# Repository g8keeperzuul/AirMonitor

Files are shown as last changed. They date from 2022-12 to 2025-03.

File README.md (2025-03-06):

# AirMonitor #
## Indoor Environmental Sensor ##

Overview | Details
---|---
Language: | C++ 
IDE: | Platform.io (VS Code + Platform.io extension)
Microcontroller: |  Adafruit Feather M0

This custom device connects to wifi and publishes sensor readings via MQTT at the set refresh rate frequency.

This device will send Home Assistant compatible discovery messages via MQTT. It can be configured via special MQTT topics.

The software is modular and designed to be reused. It sacrifices simplicity, RAM and flash in order to minimize the amount of developer time needed to get a robust Home Assistant compliant MQTT device working. 
[Start here](lib/mqtt-ha-helper/README.md) to learn how to use the [mqtt-ha-helper](lib/mqtt-ha-helper/mqtt-ha-helper.cpp) to provide auto-discovery for sensors.
For providing auto-discovery for [static device diagnostics](lib/mqtt-ha-helper/Discovery_DiagnosticFact.md) as well as [measurable diagnostics](lib/mqtt-ha-helper/Discovery_MeasurableDiagnostic.md), the steps are slightly different. Finally to support interactive controls and remote configuration via MQTT, the device will need to listen on topics and provide state updates. The details on how to do so are [here](lib/mqtt-ha-helper/Discovery_Control.md).

Auto-discovery for:
* [sensors (start here)](lib/mqtt-ha-helper/README.md)
* [diagnostic facts](lib/mqtt-ha-helper/Discovery_DiagnosticFact.md)
* [measurable diagnostics](lib/mqtt-ha-helper/Discovery_MeasurableDiagnostic.md)
* [controls](lib/mqtt-ha-helper/Discovery_Control.md)

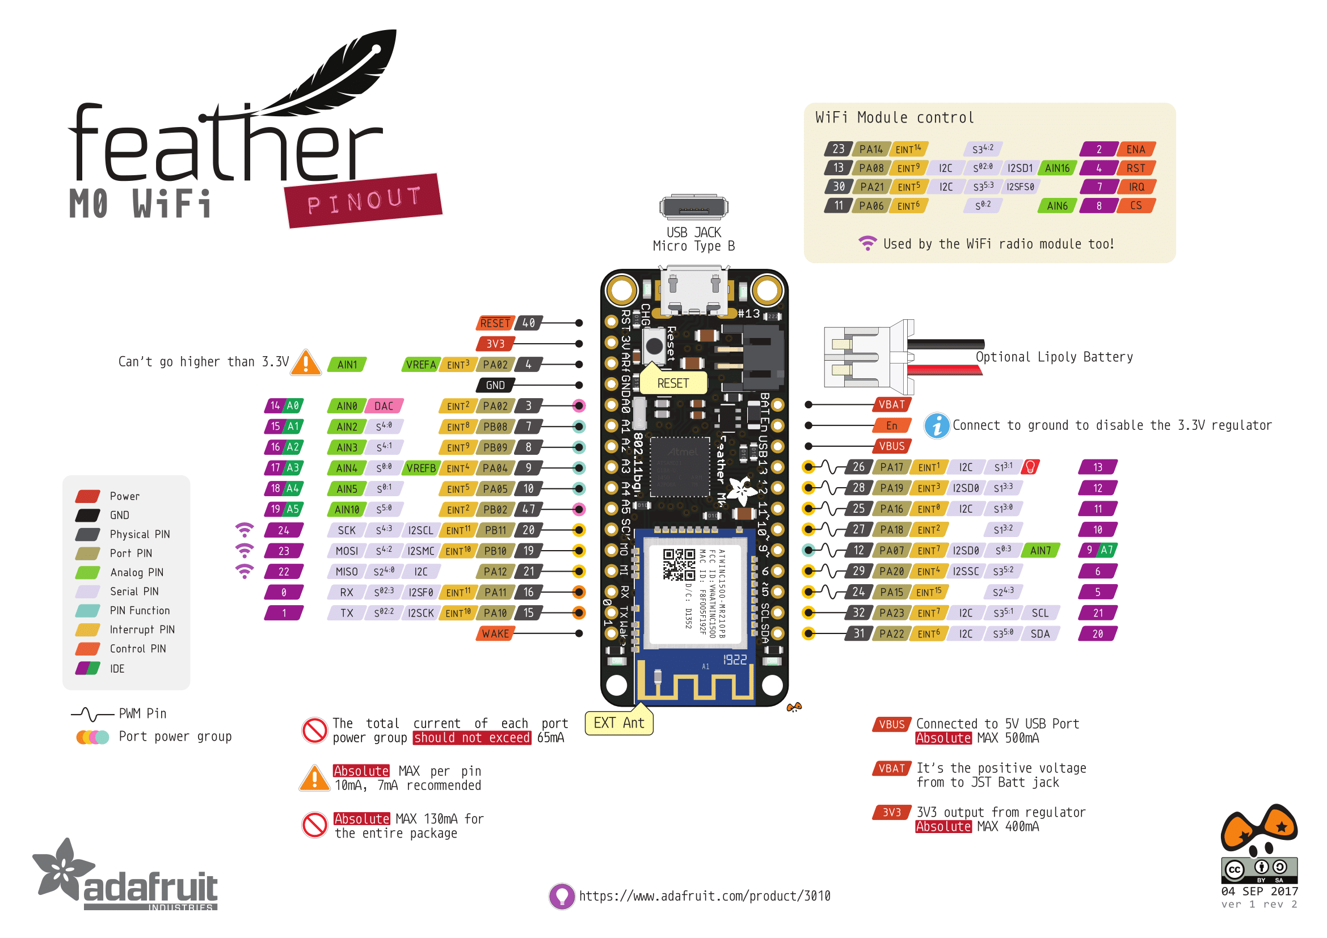
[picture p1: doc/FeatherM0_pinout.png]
Adafruit Feather M0+


Sensor | Measures...
---|---
SHT40 | humidity (% RH), temperature (C)
DPS310 | temperature (C), pressure (hectopascal, hPa), altitude computed
PM2.5 | particulate matter (Particles > 0.3um, 0.5um, 1.0um, 2.5um, 5.0um, 10.0um / 0.1L air); **AQI computed**
SCD30 | carbon dioxide (PPM direct from sensor), humidity (% RH), temperature (C)

[For physical build details, see here](doc/physical_build.md).

## How the Device Publishes Sensor State ##

MQTT Topic:
```
homeassistant/{device_type}/{device_id}/state 
homeassistant/sensor/featherm0/state
```

Sensor State Payload:
```
{
  "temperature": 22.05,
  "humidity": 38.25,
  "pressure": 989.4,
  "pressure_details": {
    "temperature": 21.25,
    "altitude": 281.3
  },
  "pm1": 1,
  "pm25": 1,
  "pm10": 1,
  "aqi": 4,
  "aqi_details": {
    "count_gt_03": 228,
    "count_gt_05": 68,
    "count_gt_10": 2,
    "count_gt_25": 0,
    "count_gt_50": 0,
    "count_gt_100": 0
  },
  "carbon_dioxide": 954,
  "carbon_dioxide_details": {
    "temperature": 23.5,
    "humidity": 35.54
  }
}
```

### Sensors Discovery ###

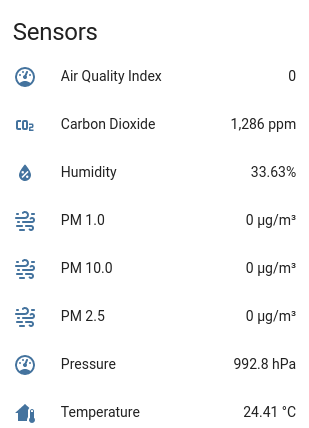
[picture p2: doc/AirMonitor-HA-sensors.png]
Sensors


All of the following sensors use the common sensor state topic (see below):

Sensor Discovery: 
```
homeassistant/sensor/featherm0/carbon_dioxide/config
homeassistant/sensor/featherm0/aqi/config
homeassistant/sensor/featherm0/pm1/config
homeassistant/sensor/featherm0/pm25/config
homeassistant/sensor/featherm0/pm10/config
homeassistant/sensor/featherm0/pressure/config
homeassistant/sensor/featherm0/humidity/config
homeassistant/sensor/featherm0/temperature/config
```

## How the Device Publishes Diagnostics ##

```
homeassistant/{device_type}/{device_id}/diagnostics
homeassistant/sensor/featherm0/diagnostics
```

Configuration State Payload:
```
{ 
"wifi_rssi": -42, 
"wifi_ip": "10.0.0.130", 
"wifi_mac": "96:e6:f1:05:f0:f8",
"sht40_heater_intensity": "Disabled", 
"sht40_heater_duration": 0, 
"sht40_precision": "High"
}
```

### Diagnostics Discovery ###
```
homeassistant/sensor/featherm0/wifi_rssi/config
homeassistant/sensor/featherm0/wifi_ip/config
homeassistant/sensor/featherm0/wifi_mac/config
homeassistant/sensor/featherm0/sht40_heater_intensity/config
homeassistant/sensor/featherm0/sht40_heater_duration/config
homeassistant/sensor/featherm0/sht40_precision/config
```

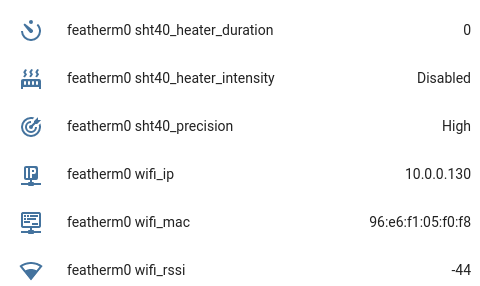
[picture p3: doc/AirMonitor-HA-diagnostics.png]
Diagnostics


## How the Device Publishes Controls ##

Controls/configuration must listen on topics to accept updates (setter or command topics) and reflect those changes back to the UI (getter or state topics). Unlike sensors or diagnostics, controls have a dedicated read and write topic per control that carry a single raw value such as an integer (not JSON).

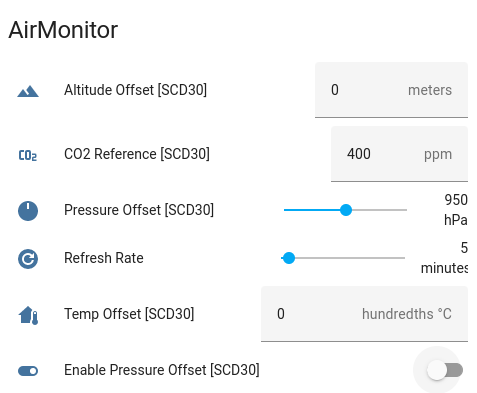
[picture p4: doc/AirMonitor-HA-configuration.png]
Controls


### Altitude Offset ###

Discovery: 
```
homeassistant/number/featherm0_altitude_offset/config
```
Altitude offset state: 
```
homeassistant/number/featherm0/altitude_offset/get
```
Altitude offset command: 
```
homeassistant/number/featherm0/altitude_offset/set
```

### Ambient Pressure Calibration ###

Discovery: 
```
homeassistant/switch/featherm0/use_pressure_offset/config
```
Use ambient pressure state: 
```
homeassistant/switch/featherm0/use_pressure_offset/get
```
Use ambient pressure command: 
```
homeassistant/switch/featherm0/use_pressure_offset/set
```

### Temperature Offset ###
Discovery: 
```
homeassistant/number/featherm0/temperature_offset/config
```
Temp Offset state: 
```
homeassistant/number/featherm0/temperature_offset/get
```
Temp Offset command: 
```
homeassistant/number/featherm0/temperature_offset/set
```

### Refresh Rate ###
Discovery: 
```
homeassistant/number/featherm0/refreshrate/config
```
Refresh rate state: 
```
homeassistant/number/featherm0/refreshrate/get
```
Refresh rate command: 
```
homeassistant/number/featherm0/refreshrate/set
```

### CO2 Calibration ###
Discovery: 
```
homeassistant/number/featherm0/co2_reference/config
```
Refresh rate state: 
```
homeassistant/number/featherm0/co2_reference/get
```
Refresh rate command: 
```
homeassistant/number/featherm0/co2_reference/set
```
See [how-to calibrate](doc/how-to-calibrate.md) for details.

## Software Dependencies ##

Feature | Library | Release
---|---|---
Wifi connectivity | https://github.com/arduino-libraries/WiFi101 | v0.16.1
MQTT connectivity | https://github.com/256dpi/arduino-mqtt | v2.5.0
DPS310 Barometric Pressure | https://github.com/adafruit/Adafruit_DPS310 | v1.1.1
SHT40 Temperature and Humidity | https://github.com/adafruit/Adafruit_SHT4X | v1.0.1
PM2.5 Air Quality | https://github.com/adafruit/Adafruit_PM25AQI | v1.0.6
SCD30 Carbon Dioxide | https://github.com/adafruit/Adafruit_SCD30 | v1.0.8

## Home Assistant Customizations ##

Update the default labels in the Home Assistant dashboard:
```
homeassistant:
  customize:
    sensor.featherm0_humidity:
      friendly_name: Humidity
    sensor.featherm0_temperature:
      friendly_name: Temperature
    sensor.featherm0_pressure:
      friendly_name: Pressure
    sensor.featherm0_aqi:
      friendly_name: Air Quality Index
    sensor.featherm0_pm1:
      friendly_name: PM 1.0
    sensor.featherm0_pm25:
      friendly_name: PM 2.5
    sensor.featherm0_pm10:
      friendly_name: PM 10.0
    sensor.featherm0_carbon_dioxide:
      friendly_name: Carbon Dioxide
    
    number.featherm0_altitude_offset:
      friendly_name: Altitude Offset [SCD30]
    number.featherm0_co2_reference:
      friendly_name: CO2 Reference [SCD30]
    number.featherm0_pressure_offset:
      friendly_name: Pressure Offset [SCD30]
    switch.featherm0_use_pressure_offset:
      friendly_name: Enable Pressure Offset [SCD30]
    number.featherm0_refreshrate:
      friendly_name: Refresh Rate
    number.featherm0_temperature_offset:
      friendly_name: Temp Offset [SCD30]
```
---
Tips:

To enable serial logging, see [log.h](lib/log/log.h)

To customize network configuration, copy [sample-env.h](src/sample-env.h) to env.h and apply your own local wifi and MQTT broker details.

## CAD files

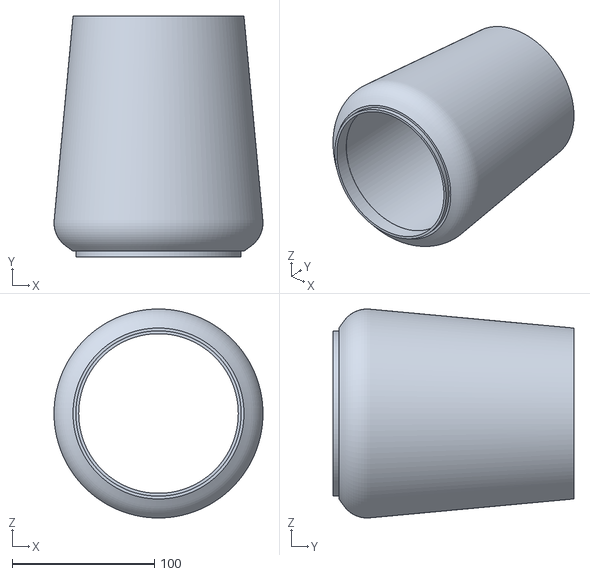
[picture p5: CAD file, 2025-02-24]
content/3d-model/Env-Sensor-Enclosure-body.stl
146.7 x 169.0 x 146.7

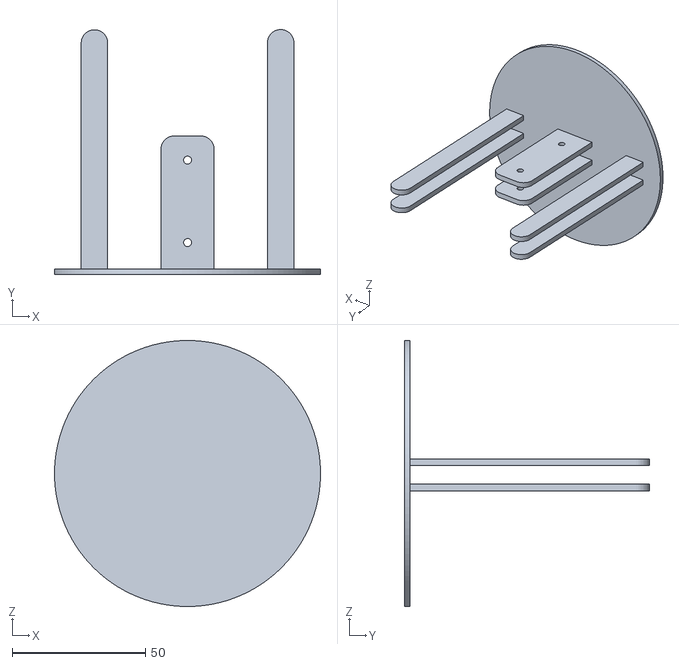
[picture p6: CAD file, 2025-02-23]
content/3d-model/Env-Sensor-Enclosure-mount.stl
100.0 x 92.1 x 100.0

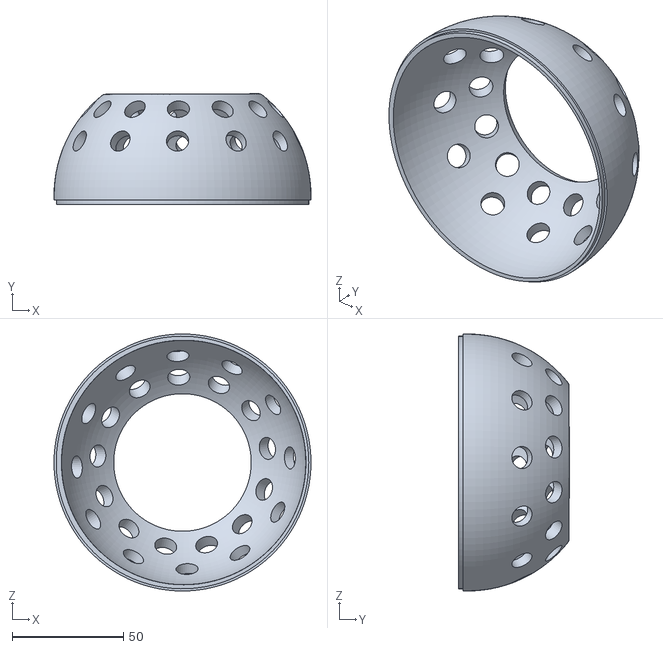
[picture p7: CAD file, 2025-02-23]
content/3d-model/Env-Sensor-Enclosure fan cover 2.stl
115.6 x 49.7 x 115.6

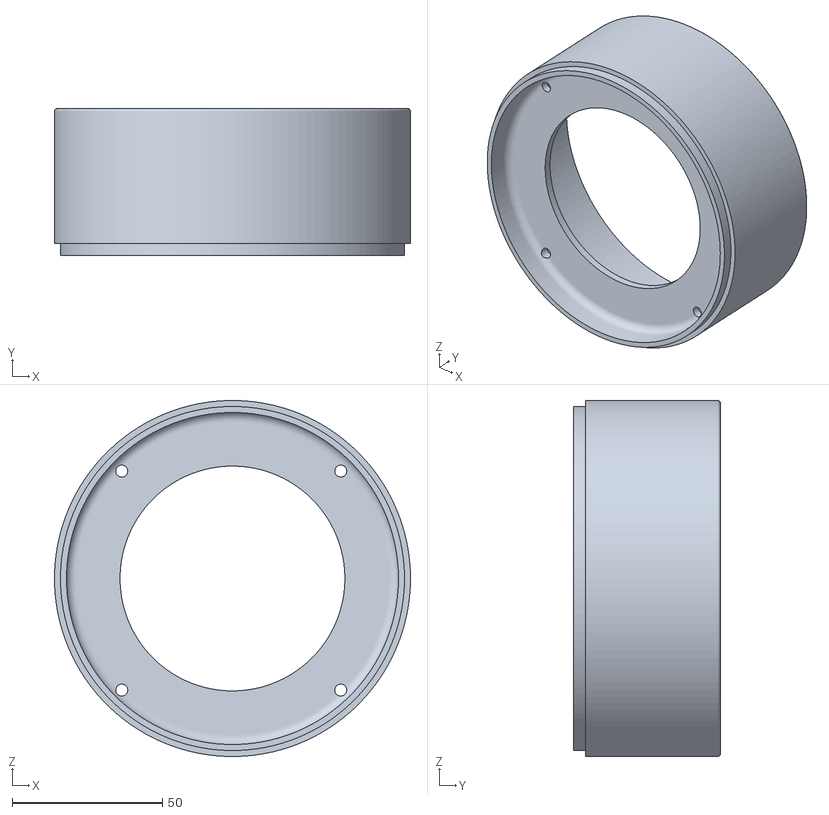
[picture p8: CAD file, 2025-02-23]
content/3d-model/Env-Sensor-Enclosure-shroud.stl
118.6 x 49.0 x 118.6

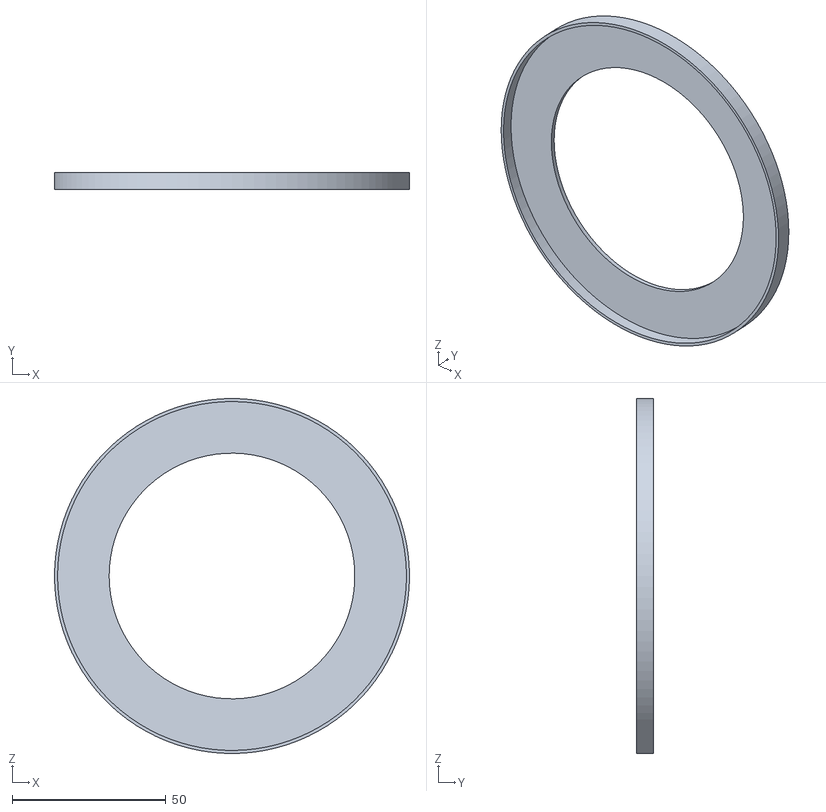
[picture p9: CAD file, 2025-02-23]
content/3d-model/Env-Sensor-Enclosure-open-fan-cover.stl
115.6 x 5.50 x 115.6

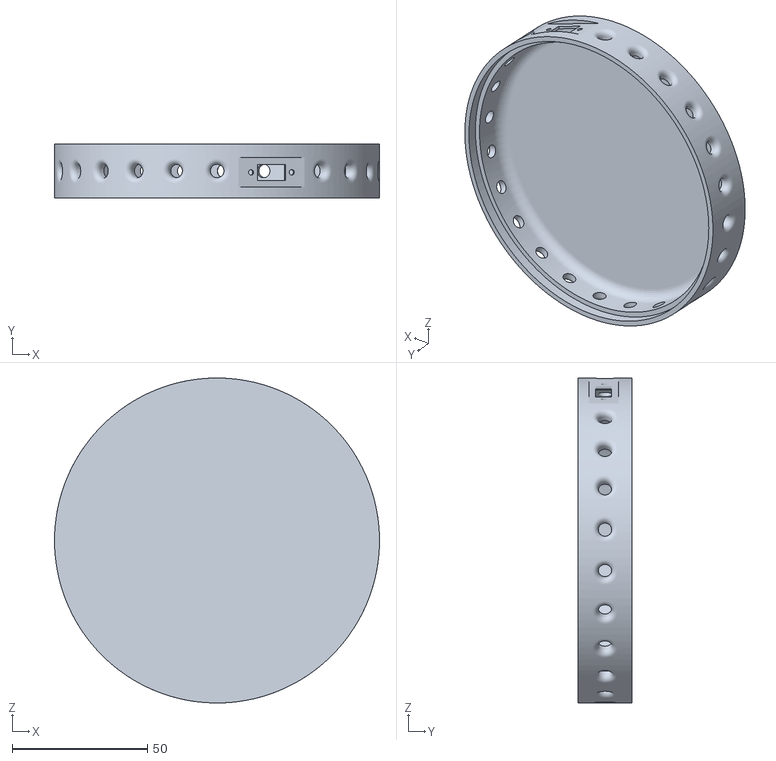
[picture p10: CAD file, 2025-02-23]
content/3d-model/Env-Sensor-Enclosure-base.stl
120.1 x 20.0 x 120.1

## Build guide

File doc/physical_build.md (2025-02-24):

# Physical Build #

This device is based on the ATSAMD21G18 ARM Cortex M0 processor paired with an Atmel ATWINC1500 wifi module. Since the device is meant to run off of mains power, the power savings and sleep features are irrelevant. More importantly, this chip has  32K of RAM and 256K of FLASH - most of which is needed by the custom software and all the necessary library dependencies for the various sensors (FLASH is ~95% utilized). 

The first enclosure used a simple project box with a nice, quiet Noctua fan. The fan is needed for two reasons: 1) it draws in air to that the particulate counter gets an accurate reading and 2) it moves the warm air out to ensure an accurate temperature and humidity reading. 

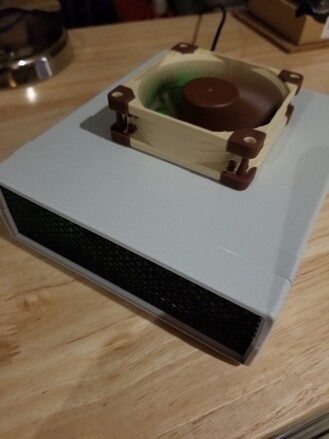
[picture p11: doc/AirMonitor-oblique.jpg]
First enclosure

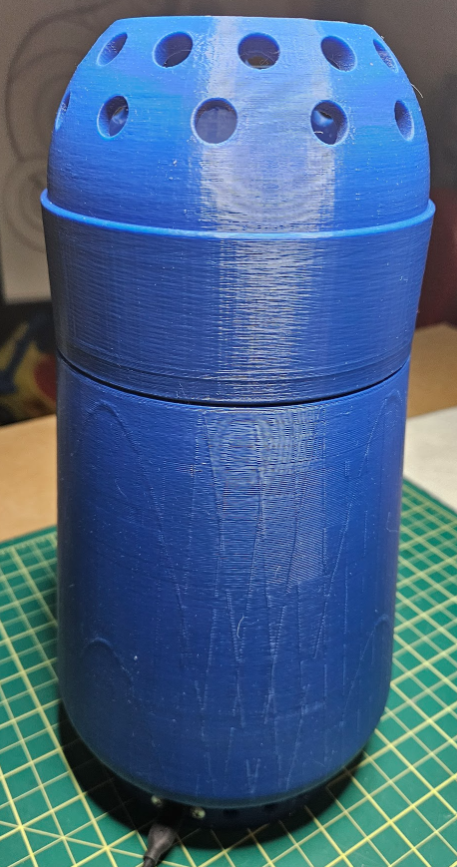
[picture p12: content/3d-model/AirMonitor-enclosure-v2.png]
Custom 3D enclosure


The custom designed case was inspired by [Apple's trashcan](https://duckduckgo.com/?q=apple+trashcan&iax=images&ia=images). Air is drawn in with the same Noctua fan at the top and it escapes via holes at the base.

The circuit boards remain mounted on cardboard as with the version 1 design, but this time both the AirMonitor board and RadiationWatcher boards are mounted within the cylinder.

The build was drastically simplified by using more expensive variants of the sensors that included i2c interfaces. Therefore the build is much like LEGOs, simply daisy chain a number of i2c components together. 

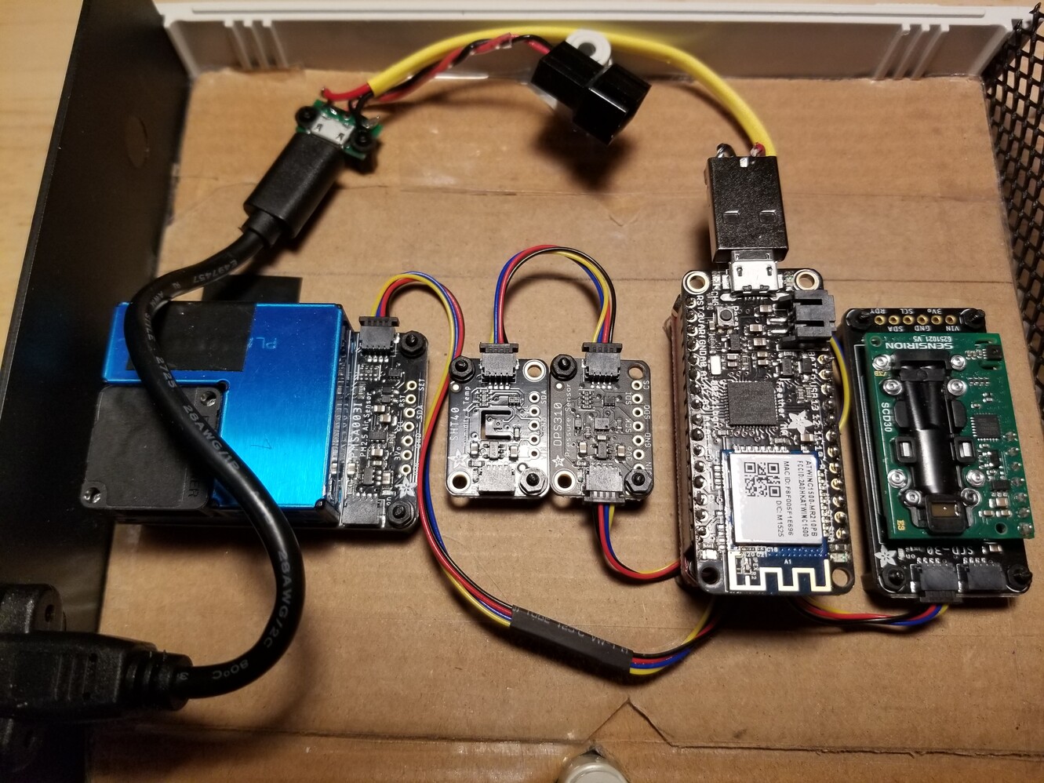
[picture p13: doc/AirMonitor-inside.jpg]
Components

From left to right: PM2.5 air quality sensor, SHT40 temperature and humidity, DPS310 pressure, Feather M0, and SCD-30 CO<sup>2</sup> sensor. Under the Feather M0 is a i2c daughterboard.

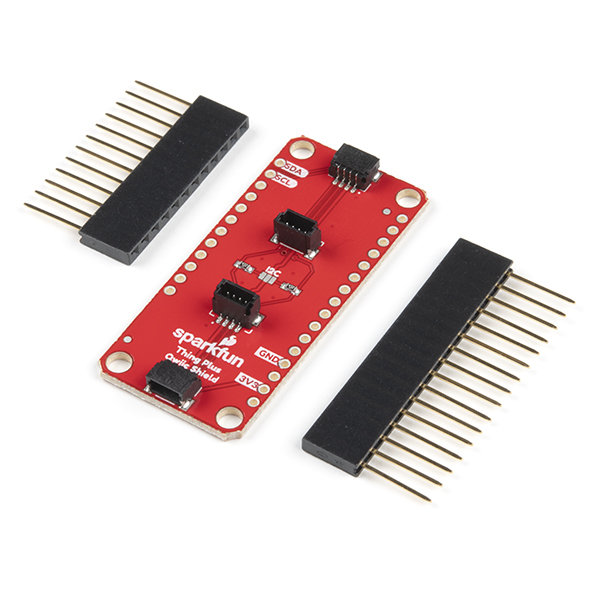
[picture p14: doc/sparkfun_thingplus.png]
i2c Adapter


The I2C adapter daughterboard hiding under the Feather M0.

## Hardware Parts List ##

Component | Detail | Interface | Reference
---|---|---|---
Microcontroller | Adafruit Feather M0 with ATWINC1500 wireless module | n/a | https://www.adafruit.com/product/3010
I2C Adapter | Sparkfun Thing plus | Feather daughterboard | https://www.sparkfun.com/products/16790
Barometric Pressure sensor | Adafruit DPS310 | i2c | https://www.adafruit.com/product/4494
Temperature and Humidity sensors | Adafruit Sensiron SHT40 | i2c | https://www.adafruit.com/product/4885
PM 2.5 Air Particulate sensor | Adafruit PMSA003I | i2c | https://www.adafruit.com/product/4632
Carbon Dioxide sensor | Adafruit SCD-30 - NDIR CO2 | i2c | https://www.adafruit.com/product/4867
Fan | Noctua NF-A8 5V, Premium Quiet Fan with USB Power Adaptor Cable, 3-Pin, 5V Version (80mm, Brown). 10 ohm resistor added to power cable. | 5v/gnd | https://www.amazon.ca/gp/product/B07DXNT9J9

Feather M0 pinout

## Enclosure ##

The final step is fitting all these components into an enclosure. One important consideration is to ensure you gave proper ventillation. Obviously the gas and air quality sensors need airflow to function correctly. Additionally mechanically exchanging the air with a fan will prevent a temperature buildup within the case which will result in sensor inaccuracies. Small fans have an high-pitched whine to them and my first attempt was a complete annoyance. I needed something a lot quieter.
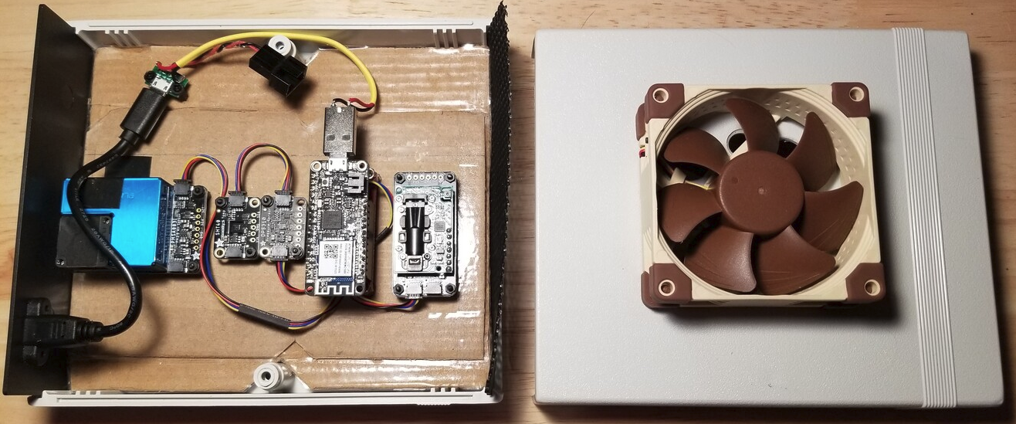
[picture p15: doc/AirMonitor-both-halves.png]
Enclosure opened

I found this new Noctua 80mm fan. They are very expensive ($20 each compared to $4 each) but are perfectly quiet and have rubber isolating attachments to dampen vibrations. 

The version 2 enclosure is inspired by the old Apple Mac Pro trashcan. The circuit boards are mounted on cardboard as they were with version 1, but this time they are oriented vertically. 
There was enough space within that I mounted the [AirMonitor](https://github.com/g8keeperzuul/AirMonitor) board on one side, and the [RadiationWatcher](https://github.com/g8keeperzuul/RadiationWatcher) on the other. There is still one USB power cable coming into the enclosure which is split between the fan and two devices. 
In order to keep the fan as quiet as possible, a 10 ohm resistor was inserted into the fan power cable. It allows enough air movement while making it as silent as possible. 

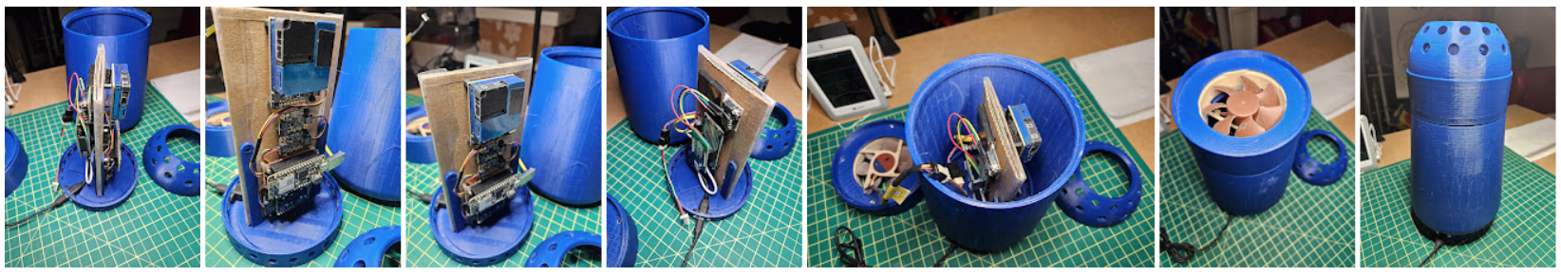
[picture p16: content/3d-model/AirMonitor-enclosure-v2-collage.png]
Version 2 enclosure physical

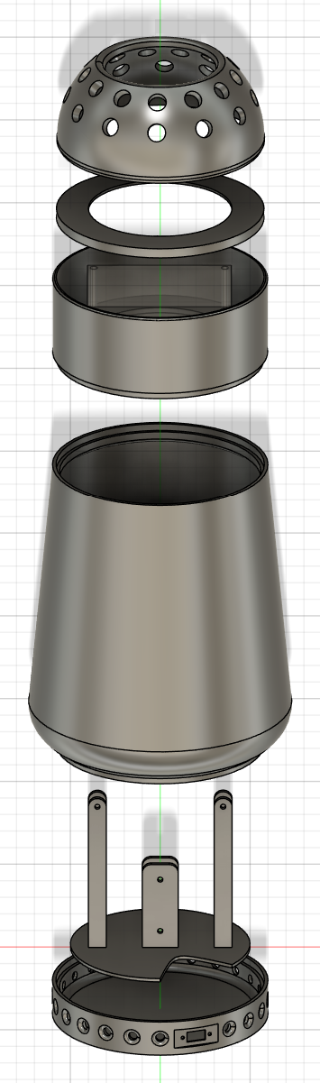
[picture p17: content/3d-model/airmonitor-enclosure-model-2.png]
Version 2 enclosure 3D model


3D Models:
1. [AirMonitor+RadiationWatcher base](../content/3d-model/Env-Sensor-Enclosure-base.stl)
2. [AirMonitor+RadiationWatcher mount](../content/3d-model/Env-Sensor-Enclosure-mount.stl)
3. [AirMonitor+RadiationWatcher body](../content/3d-model/Env-Sensor-Enclosure-body.stl)
4. [AirMonitor+RadiationWatcher fan enclosure](../content/3d-model/Env-Sensor-Enclosure-shroud.stl)
5. [AirMonitor+RadiationWatcher fan cover](../content/3d-model/Env-Sensor-Enclosure-open-fan-cover.stl)
6. [AirMonitor+RadiationWatcher domed topper](../content/3d-model/Env-Sensor-Enclosure%20fan%20cover%202.stl)

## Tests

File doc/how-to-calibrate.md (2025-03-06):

# Calibrating the CO2 Sensor

## Step 1: Apply a temperature correction

The SCD30 CO2 sensor has its own temperature and humidity sensors. The temperature is typically slightly higher than nominal due to its proximity to the sensors heating element.
You can see the the CO2 internal temperature sensor on line 23 compared to the independent temperature sensor on line 2.
This skewed temperature affects the accuracy of the CO2 and humidity reading. Correcting the temperature will have a positive affect on both other readings. 

```
01 {
02   "temperature": 22.52,
03   "humidity": 49.36,
04   "pressure": 1002.7,
05   "pressure_details": {
06     "temperature": 21.71,
07     "altitude": 110.7
08   },
09   "pm1": 5,
10   "pm25": 8,
11   "pm10": 8,
12   "aqi": 32,
13   "aqi_details": {
14     "count_gt_03": 885,
15     "count_gt_05": 282,
16     "count_gt_10": 54,
17     "count_gt_25": 2,
18     "count_gt_50": 0,
19     "count_gt_100": 0
20   },
21   "carbon_dioxide": 433,
22   "carbon_dioxide_details": {
23     "temperature": 23.33,
24     "humidity": 47.75
25   }
26 }
```

The temperature offset is exposed as a device configuration setting. It is specified in one hundredths of a degree.
So to (decrease) the CO2 temperature sensor by 1C specify 100 as the temperature offset.

```
Publish 100 to : homeassistant/number/featherm0/temperature_offset/set
```

## Step 2: Calibrate the CO2 sensor

The SCD30 CO2 sensor should already be pre-calibrated. However there are two ways to do it yourself. The automatic way and the forced way.
The forced way is preferrable, but requires that you know the CO2 PPM concentration that the SCD30 is sensing. Use [420 ppm](https://www.co2.earth/annual-co2) as a default. 

a) Expose the device to outside air, e.g. by placing it close to an open window or outside. Direct sun light, extreme temperatures, and strong air flow have to be prevented.
b) Confirm the stability of ambient conditions (temperature and humidity) via the MQTT messages (the embedded temerature and humidity readings nested under "carbon_dioxide_details" are specific to the SCD30):
``` ... "carbon_dioxide":  609, "carbon_dioxide_details": {"temperature": 20.59, "humidity": 37.31} ... ```
c) After 2 minutes, apply the reference value 420 ppm.
To set this, simply set the CO2 Reference PPM in the device configuration setting. 
```
Publish the integer value 420 to : homeassistant/number/featherm0/co2_reference/set
```

The automatic way requires about 5 days of continuous sensing indoors and out and this mode is not exposed via the configuration interface. 

You can use the Home Assistant configuration UI instead of manually publishing to MQTT.

![AirMonitor configuration](AirMonitor-HA-configuration.png)

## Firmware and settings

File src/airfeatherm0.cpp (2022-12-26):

#include "airfeatherm0.h"

/*
Built for Adafruit Feather M0 with ATWINC1500 wireless module 
https://www.adafruit.com/product/3010
*/

// *** Global Variables ***
WiFiClient wificlient;
MQTTClient mqttclient(768); // default is 128 bytes;  https://github.com/256dpi/arduino-mqtt#notes

unsigned long refresh_rate = 60000; // 1 minutes default; frequency of sensor updates in milliseconds

/*
  Since the fully constructed list of discovery_config (topics and payloads) consumes considerable RAM, reduce it to just the facts.
  Generate each discovery_config one at a time at the point of publishing the message in order to conserve RAM.
  Once everything is successfully published, purge list contents (no longer needed).
*/
std::vector<discovery_metadata> discovery_metadata_list;                                            // list of data used to construct discovery_config for sensor discovery
std::vector<discovery_config_metadata> discovery_config_metadata_list;                              // list of data used to construct discovery_config for config/control discovery
std::vector<discovery_measured_diagnostic_metadata> discovery_measured_diagnostic_metadata_list;    // list of data used to construct discovery_config for sensor measured diagnostics (like RSSI)
std::vector<discovery_fact_diagnostic_metadata> discovery_fact_diagnostic_metadata_list;            // list of data used to construct discovery_config for fact diagnostics (like IP address)

// Last will and testament topic
const std::string AVAILABILITY_TOPIC = buildAvailabilityTopic("sensor", std::string(DEVICE_ID)); // homeassistant/sensor/featherm0/availability

const std::string DIAGNOSTIC_TOPIC = buildDiagnosticTopic("sensor", std::string(DEVICE_ID)); // homeassistant/sensor/featherm0/diagnostics

// All sensor updates are published in a single complex json payload to a single topic
const std::string STATE_TOPIC = buildStateTopic("sensor", std::string(DEVICE_ID)); // homeassistant/sensor/featherm0/state

// *****************************

/*
  device_class : https://developers.home-assistant.io/docs/core/entity/sensor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
                 https://www.home-assistant.io/integrations/sensor/#device-class
  has_sub_attr : true if you want to provide sub attributes under the main attribute
  icon : https://materialdesignicons.com/
  unit : (depends on device class, see link above)
*/
// build discovery message - step 1 of 4
std::vector<discovery_metadata> getAllDiscoveryMessagesMetadata(){
  discovery_metadata temp, humidity, pressure, aqi, pm1, pm25, pm10, co2;

  // default device_type = "sensor"
  // default sub_attr = false

  temp.device_class = "temperature";  
  temp.icon = "mdi:home-thermometer";
  temp.unit = "°C";

  humidity.device_class = "humidity";  
  humidity.icon = "mdi:water-percent";
  humidity.unit = "%";

  pressure.device_class = "pressure";
  pressure.icon = "mdi:gauge";
  pressure.unit = "hPa";

  aqi.device_class = "aqi";
  aqi.has_sub_attr = true; 
  aqi.icon = "mdi:gauge";
  aqi.unit = "";

  pm1.device_class = "pm1";
  pm1.icon = "mdi:weather-dust";
  pm1.unit = "µg/m³";

  pm25.device_class = "pm25";
  pm25.icon = "mdi:weather-dust";
  pm25.unit = "µg/m³";

  pm10.device_class = "pm10";
  pm10.icon = "mdi:weather-dust";
  pm10.unit = "µg/m³";

  co2.device_class = "carbon_dioxide";
  co2.has_sub_attr = true; 
  co2.icon = "mdi:molecule-co2";
  co2.unit = "ppm";  

  std::vector<discovery_metadata> dm = { temp, humidity, pressure, aqi, pm1, pm25, pm10, co2 };  
  return dm;
}

// build discovery config/control message - step 1 of 4
std::vector<discovery_config_metadata> getAllDiscoveryConfigMessagesMetadata(){
  discovery_config_metadata tempoffset, altoffset, co2ref, useambpres, presoffset, refrate;

  tempoffset.device_type = "number";
  tempoffset.control_name = "temperature_offset";
  tempoffset.custom_settings = "\"min\": 0, \"max\": 10000, \"step\": 10, \"initial\": 0";
  tempoffset.icon = "mdi:home-thermometer";
  tempoffset.unit = "hundredths °C";  
  //tempoffset.set_topic = if not set, it will be generated
  //tempoffset.get_topic = if not set, it will be generated

  // pressure offset is deactivated by setting to 0, but allowable range is 700-1200
  // so use a switch to turn off (setting to 0)

  useambpres.device_type = "switch";
  useambpres.control_name = "use_pressure_offset";
  useambpres.custom_settings = "";
  useambpres.icon = "mdi:toggle-switch";
  useambpres.unit = "";

  presoffset.device_type = "number";
  presoffset.control_name = "pressure_offset";
  presoffset.custom_settings = "\"min\": 700, \"max\": 1200, \"step\": 10, \"initial\": 950";
  presoffset.icon = "mdi:knob";
  presoffset.unit = "hPa"; // equivalent to mBar  

  altoffset.device_type = "number";
  altoffset.control_name = "altitude_offset";
  altoffset.custom_settings = "\"min\": -450, \"max\": 8850, \"step\": 5, \"initial\": 0";
  altoffset.icon = "mdi:image-filter-hdr";
  altoffset.unit = "meters";

  co2ref.device_type = "number";
  co2ref.control_name = "co2_reference";
  co2ref.custom_settings = "\"min\": 400, \"max\": 2000, \"step\": 1, \"initial\": 900";
  co2ref.icon = "mdi:molecule-co2";
  co2ref.unit = "ppm";    

  refrate.device_type = "number";
  refrate.control_name = "refreshrate";
  refrate.custom_settings = "\"min\": 1, \"max\": 60, \"step\": 1";
  refrate.icon = "mdi:refresh-circle";
  refrate.unit = "minutes";

  std::vector<discovery_config_metadata> dcm = { tempoffset, altoffset, co2ref, useambpres, presoffset, refrate };  
  return dcm;
}

std::vector<discovery_measured_diagnostic_metadata> getAllDiscoveryMeasuredDiagnosticMessagesMetadata(){
  discovery_measured_diagnostic_metadata rssi;

  rssi.device_type = "sensor";
  rssi.device_class = "";  // battery | date | duration | timestamp | ... In some cases may be "None" - https://developers.home-assistant.io/docs/core/entity/sensor/#available-device-classes    
  //rssi.state_class = "measurement";  Accept default
  rssi.diag_attr = "wifi_rssi";
  rssi.icon = "mdi:wifi-strength-2";  // https://materialdesignicons.com/
  rssi.unit = ""; // RSSI is unitless
  
  std::vector<discovery_measured_diagnostic_metadata> dmdm = { rssi };  
  return dmdm;
}

std::vector<discovery_fact_diagnostic_metadata> getAllDiscoveryFactDiagnosticMessagesMetadata(){
  discovery_fact_diagnostic_metadata ip, mac, sht40_heater_intensity, sht40_heater_duration, sht40_precision;
  
  ip.device_type = "sensor";
  ip.diag_attr = "wifi_ip";
  ip.icon = "mdi:ip-network";  

  mac.device_type = "sensor";
  mac.diag_attr = "wifi_mac";
  mac.icon = "mdi:network-pos";  

  sht40_heater_intensity.device_type = "sensor";
  sht40_heater_intensity.diag_attr = "sht40_heater_intensity";
  sht40_heater_intensity.icon = "mdi:radiator";  

  sht40_heater_duration.device_type = "sensor";
  sht40_heater_duration.diag_attr = "sht40_heater_duration";
  sht40_heater_duration.icon = "mdi:camera-timer";

  sht40_precision.device_type = "sensor";
  sht40_precision.diag_attr = "sht40_precision";
  sht40_precision.icon = "mdi:bullseye-arrow";   

  std::vector<discovery_fact_diagnostic_metadata> dfdm = { ip, mac, sht40_heater_intensity, sht40_heater_duration, sht40_precision };  
  return dfdm;
}

/* If the buildShortDevicePayload() is used, and there are no config/controls that use the full device payload, then HA will never see it.
   So the full device payload is used for both kinds of discovery message. The short version is used for diagnostic messages because they 
   are always accompanied by sensor and/or control messages. */

// build discovery message - step 3 of 4
discovery_config getDiscoveryMessage(discovery_metadata disc_meta){
    return getDiscoveryMessage(disc_meta, DEVICE_ID, buildDevicePayload(DEVICE_NAME, getMAC(), DEVICE_MANUFACTURER, DEVICE_MODEL, DEVICE_VERSION), AVAILABILITY_TOPIC, STATE_TOPIC);
}

// build discovery config/control message - step 3 of 4
discovery_config getDiscoveryMessage(discovery_config_metadata disc_meta){  
  return getDiscoveryConfigMessage(disc_meta, DEVICE_ID, buildDevicePayload(DEVICE_NAME, getMAC(), DEVICE_MANUFACTURER, DEVICE_MODEL, DEVICE_VERSION), AVAILABILITY_TOPIC);
}

// build discovery measured diagnostic message - step 3 of 4
discovery_config getDiscoveryMessage(discovery_measured_diagnostic_metadata disc_meta){  
  return getDiscoveryMeasuredDiagnosticMessage(disc_meta, DEVICE_ID, buildShortDevicePayload(DEVICE_NAME, getMAC()), AVAILABILITY_TOPIC, DIAGNOSTIC_TOPIC);
}

// build discovery diagnostic fact message - step 3 of 4
discovery_config getDiscoveryMessage(discovery_fact_diagnostic_metadata disc_meta){  
  return getDiscoveryFactDiagnosticMessage(disc_meta, DEVICE_ID, buildShortDevicePayload(DEVICE_NAME, getMAC()), AVAILABILITY_TOPIC, DIAGNOSTIC_TOPIC);
}


/*
  temperature                         : sensor on SHT40 in celcius
  humidity                            : sensor on SHT40 in %RH

  pressure                            : sensor on DPS310 is atmospheric pressure in hectopascal (hPa)
  pressure_details.temperature        : sensor on DPS310 (pressure sensor) in celcius
  pressure_details.altitude           : sensor on DPS310 (pressure sensor), computed altitude in meters

  aqi                                 : calculation based on PM2.5 (2.5 µ𝑚 or smaller) 
  aqi_details.count_gt_03             : number of particles with diameter greater than 0.3 µ𝑚 in 0.1L of air      
  aqi_details.count_gt_05             : number of particles with diameter greater than 0.5 µ𝑚 in 0.1L of air        
  aqi_details.count_gt_10             : number of particles with diameter greater than 1.0 µ𝑚 in 0.1L of air        
  aqi_details.count_gt_25             : number of particles with diameter greater than 2.5 µ𝑚 in 0.1L of air        
  aqi_details.count_gt_50             : number of particles with diameter greater than 5.0 µ𝑚 in 0.1L of air        
  aqi_details.count_gt_100            : number of particles with diameter greater than 10.0 µ𝑚 in 0.1L of air
  aqi_details.pm1.0                   : µg/𝑚3 assumes standard particle density (CF=1)
  aqi_details.pm2.5                   : µg/𝑚3 assumes standard particle density (CF=1)
  aqi_details.pm10                    : µg/𝑚3 assumes standard particle density (CF=1)

  carbon_dioxide                      : sensor on SCD30 in ppm
  carbon_dioxide_details.temperature  : sensor on SCD30 (CO2 sensor) in celcius
  carbon_dioxide_details.humidity     : relative humidity sensor on SCD30 (CO2 sensor) in % RH
*/
void publishSensorData(){
  
  // temp & humidity
  sht40_data sht40 = readSHT40();

  // pressure & temperature
  dps310_data dps310 = readDPS310();

  // air particulates
  PM25_AQI_Data pm25aqi_data = readPM25AQI();
  uint16_t aqi = calculateAQI(pm25aqi_data.pm25_standard); // AQI based on particulate matter 2.5 µm in diameter or smaller (PM2.5) 

  // carbon dioxide
  scd30_data scd30 = readSCD30();

      std::string payload = "{\
\"temperature\": "+to_string(sht40.temperature, "%2.2f")+", \
\"humidity\": "+to_string(sht40.relative_humidity, "%2.2f")+", \
\"pressure\": "+to_string(dps310.pressure, "%5.1f")+", \
\"pressure_details\": {\"temperature\": "+to_string(dps310.temperature, "%2.2f")+", \"altitude\": "+to_string(dps310.altitude, "%4.1f")+"}, \
\"pm1\": "+to_string(pm25aqi_data.pm10_standard)+", \
\"pm25\": "+to_string(pm25aqi_data.pm25_standard)+", \
\"pm10\": "+to_string(pm25aqi_data.pm100_standard)+", \
\"aqi\": "+to_string(aqi)+", \
\"aqi_details\": {\"count_gt_03\": "+to_string(pm25aqi_data.particles_03um)+", \
\"count_gt_05\": "+to_string(pm25aqi_data.particles_05um)+", \
\"count_gt_10\": "+to_string(pm25aqi_data.particles_10um)+", \
\"count_gt_25\": "+to_string(pm25aqi_data.particles_25um)+", \
\"count_gt_50\": "+to_string(pm25aqi_data.particles_50um)+", \
\"count_gt_100\": "+to_string(pm25aqi_data.particles_100um)+"}, \
\"carbon_dioxide\": "+to_string(scd30.CO2, "%4.0f")+", \
\"carbon_dioxide_details\": {\"temperature\": "+to_string(scd30.temperature, "%2.2f")+", \"humidity\": "+to_string(scd30.relative_humidity, "%2.2f")+"}\
}";

      const char* payload_ch = payload.c_str();

      Sprint(F("Publishing sensor readings: "));  
      Sprintln(payload_ch);
      mqttclient.publish(STATE_TOPIC.c_str(), payload_ch, NOT_RETAINED, QOS_0);  
}

void publishDiagnosticData(){

  sht40_config sht40 = readSHT40Config();

  std::string payload = "{\
\"wifi_rssi\": "+to_string(getRSSI())+", \
\"wifi_ip\": \""+getIP()+"\", \
\"wifi_mac\": \""+getMAC()+"\", \
\"sht40_heater_intensity\": \""+sht40.heater_intensity+"\", \
\"sht40_heater_duration\": "+to_string(sht40.heater_duration)+", \
\"sht40_precision\": \""+sht40.precision+"\" \
}";

  const char* payload_ch = payload.c_str();

  Sprint(F("Publishing diagnostic readings: "));  
  Sprintln(payload_ch);

  mqttclient.publish(DIAGNOSTIC_TOPIC.c_str(), payload_ch, NOT_RETAINED, QOS_0);   
}

/*
  There are config/controls that provide their own getter topic instead of the state or diagnostic topic.
  These topics will reflect the requested (via setter topic) update when a control/config change is made.
  However, they need to be periodically refreshed to keep the Home Assistant UI up-to-date even when a control isn't changed.

  homeassistant/switch/featherm0/use_pressure_offset/get
  homeassistant/number/featherm0/pressure_offset/get
  homeassistant/number/featherm0/refreshrate/get
  homeassistant/number/featherm0/temperature_offset/get
  homeassistant/number/featherm0/altitude_offset/get
  homeassistant/number/featherm0/co2_reference/get
*/
void publishConfigData(){
 for (size_t i = 0; i < discovery_config_metadata_list.size(); i++){
    String test_control_name = String(discovery_config_metadata_list[i].control_name.c_str());
    if(test_control_name.equals("use_pressure_offset")){
        if(scd30.getAmbientPressureOffset() == 0){
          publish(discovery_config_metadata_list[i].get_topic.c_str(), "OFF");
        }
        else{
          publish(discovery_config_metadata_list[i].get_topic.c_str(), "ON");
        }
    }
    else if(test_control_name.equals("pressure_offset")){
        if(scd30.getAmbientPressureOffset() == 0){
          publish(discovery_config_metadata_list[i].get_topic.c_str(), "950");
        }
        else{
          publish(discovery_config_metadata_list[i].get_topic.c_str(), String(scd30.getAmbientPressureOffset()));
        }
    }
    else if(test_control_name.equals("refreshrate")){
      publish(discovery_config_metadata_list[i].get_topic.c_str(), String(refresh_rate/1000/60));
    }
    else if(test_control_name.equals("temperature_offset")){
      publish(discovery_config_metadata_list[i].get_topic.c_str(), String(scd30.getTemperatureOffset()));
    }
    else if(test_control_name.equals("altitude_offset")){
      publish(discovery_config_metadata_list[i].get_topic.c_str(), String(scd30.getAltitudeOffset()));
    }    
    else if(test_control_name.equals("co2_reference")){
      publish(discovery_config_metadata_list[i].get_topic.c_str(), String(scd30.getForcedCalibrationReference()));
    }
    else{
      Sprint(F("WARN: Config/control state not published: ")); Sprintln(test_control_name);
    }     
  }
}


std::queue<pending_config_op> pending_ops = {};
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
void loop()
{
  mqttclient.loop(); // potential call to messageReceived()
  processMessages(); // deal with any pending_ops added by messageReceived() handler
  
  if (millis() - lastMillis > refresh_rate) {   
    lastMillis = millis();
    
    digitalWrite(LED_BUILTIN, LED_ON);
    publishOnline(AVAILABILITY_TOPIC.c_str());
    publishSensorData();    
    publishDiagnosticData();
    publishConfigData();
    digitalWrite(LED_BUILTIN, LED_OFF);
  }
  assertConnectivity(); // Runs until network and broker connectivity established and all subscriptions successful
}

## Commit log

2022-12-03 Fixed and extracted log disablement
    [airfeatherm0.cpp]
2023-08-22 Added calibration documentation
2025-02-23 Added details on new 3D printed enclosure.
    [Env-Sensor-Enclosure fan cover 2.stl, Env-Sensor-Enclosure-base.stl, Env-Sensor-Enclosure-mount.stl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]
2025-02-24 Added missing body STL model
    [Env-Sensor-Enclosure-body.stl]
